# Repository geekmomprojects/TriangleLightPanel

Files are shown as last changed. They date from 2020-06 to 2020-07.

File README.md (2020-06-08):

# TriangleLightPanel
 
Triangle LED Light Panel TriangleBoards
 
Files for modular "Nanoleaf" style connecting LED PCBs. Each triangular board contains three 4020 Side-Emitting SK6812 LEDs, which diffuse their light into a translucent acrylic cover panel. The triangular LED boards are connected via smaller rectangular connector PCBs using a system of pressure contacts and pads. 

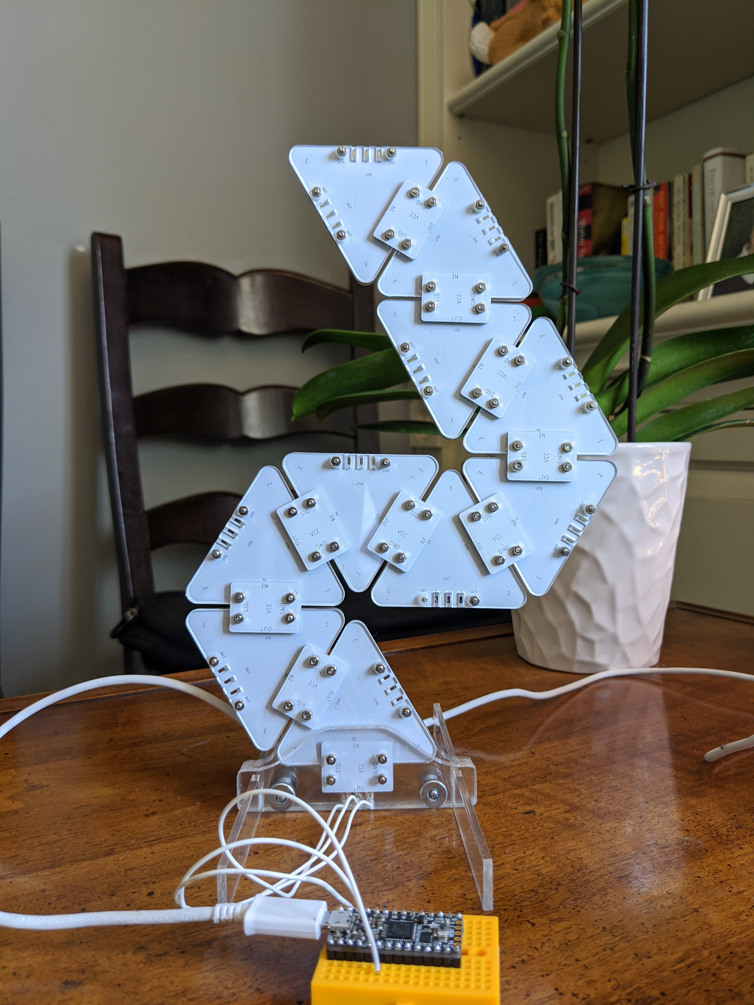
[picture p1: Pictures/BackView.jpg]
Board Connectors


This repository contains Eagle CAD files for the Triangle LED boards and connector boards. Be warned that SMT soldering 4020 side-emitting LEDs is *very* tricky if you decide to make your own. Best accomplished with solder paste and a reflow oven or hot air gun

A thin layer of 1/16" clear acrylic across the back of each Triangle PCB prevents pressure contacts from being crushed and a layer of 1/8" semi-translucent acrylic diffuses the LEDs on the front side. CAD files for each are included and will need to be laser cut. Link to best diffusion acrylic I've found to use is in the BOM.

All pieces held together with M2 screws (10mm) and nuts. The full assembly can stand freely without being wall mounted.

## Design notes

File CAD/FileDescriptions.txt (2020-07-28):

CAD Files:

"DiffusionLayerAcrylic.svg" to be cut from 1/8" semi-translucent acrylic, sits on the front of the triangle PCB to diffuse light from side emitting LEDs. 
"BufferLayerAcrylic.svg" to be cut from 1/16" clear acrylic, sits on back of triangle PCB to prevent pressure contacts from being crushed

See BOM.xls for sourcing details

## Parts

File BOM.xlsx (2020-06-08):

PCB Components
Component | Manfacturer | Part Number | Datasheet | Source | Notes
Pressure Contact | Amphenol | 10104319-009RLF | https://cdn.amphenol-icc.com/media/wysiwyg/files/drawing/10104319.pdf | https://www.digikey.com/product-detail/en/amphenol-icc-fci/10104319-009RLF/609-5377-1-ND/8555648
Side Emitting LED |  | SK6812 4020 Side Emitting RGB LED | https://www.aliexpress.com/item/32965664236.html | https://www.aliexpress.com/item/32965664236.html | Purchased "SIDE old version"
0.1 uF Capacitor (0603) | Samsung | CL10F104ZO8NNNC |  | https://www.digikey.com/product-detail/en/samsung-electro-mechanics/CL10F104ZO8NNNC/1276-1258-1-ND/3889344
Acrylic
1/8" Semi-Translucent Acrylic Sheet for LED diffusion | Rowmark | ROWMARK COLORHUES PHANTOM TRANSLUCENT ENGRAVING PLASTIC |  | https://www.jpplus.com/rowmark-colorhues-phantom-translucent-engraving-plastic
1/16" Clear Acrylic sheet to buffer pressure contacts
Hardware
M2 Screws (10mm)
M2 Nuts

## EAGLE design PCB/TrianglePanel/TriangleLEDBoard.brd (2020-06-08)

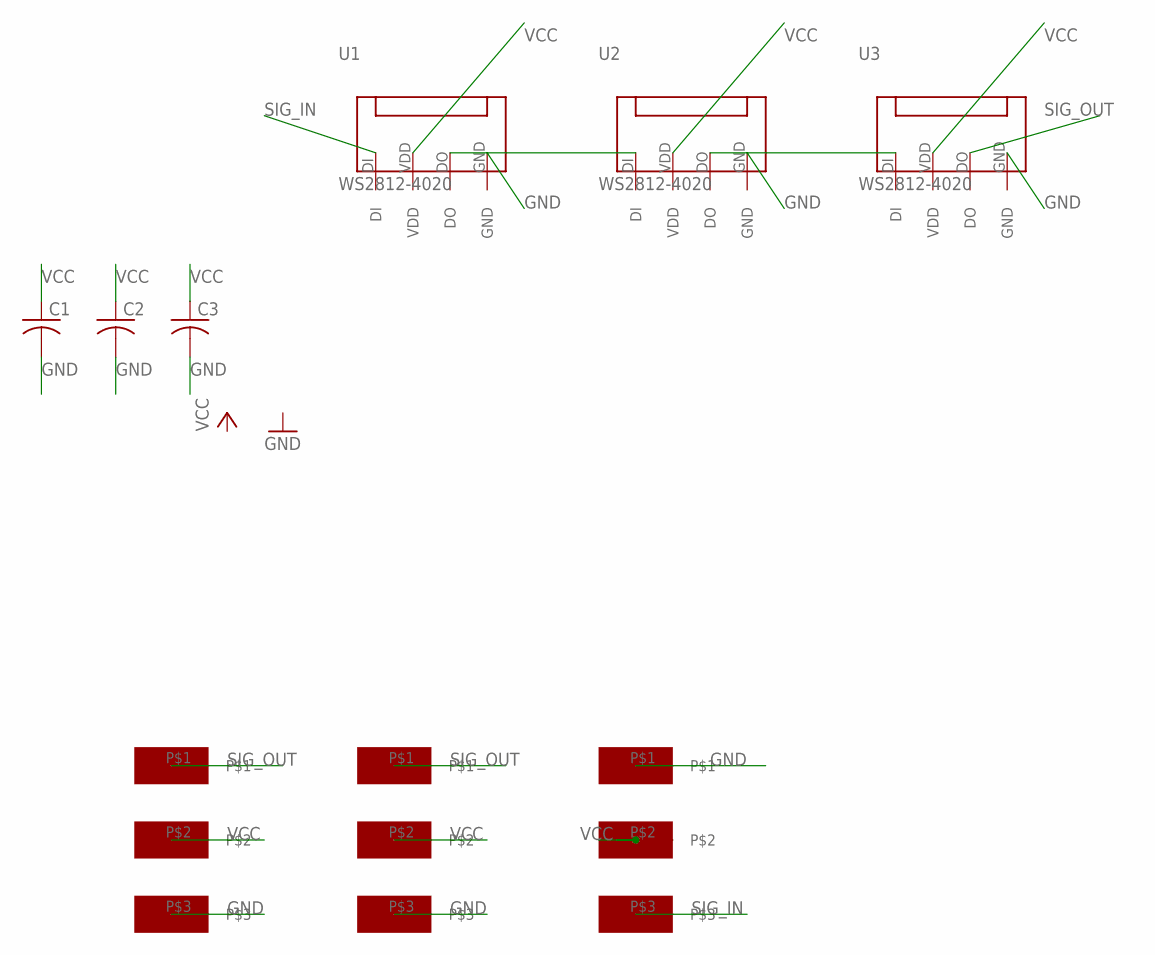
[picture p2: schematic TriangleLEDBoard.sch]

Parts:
C1, C2, C3: C-USC0603; C0603
U1, U2, U3: WS2812-4020; WS2812B_4020
U$1, U$2, U$3: 3_CONTACT_PADS_5_MM_SPACING_WITH_HOLES; RECTANGULAR_PADS_5_MM_SPACING_WITH_HOLES

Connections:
GND: C1.2, C2.2, C3.2, U1.GND, U2.GND, U3.GND, U$1.P$1, U$2.P$3, U$3.P$3
unnamed: U1.DO, U2.DI
unnamed: U2.DO, U3.DI
SIG_IN: U1.DI, U$1.P$3
SIG_OUT: U3.DO, U$2.P$1, U$3.P$1
VCC: C1.1, C2.1, C3.1, U1.VDD, U2.VDD, U3.VDD, U$1.P$2, U$2.P$2, U$3.P$2

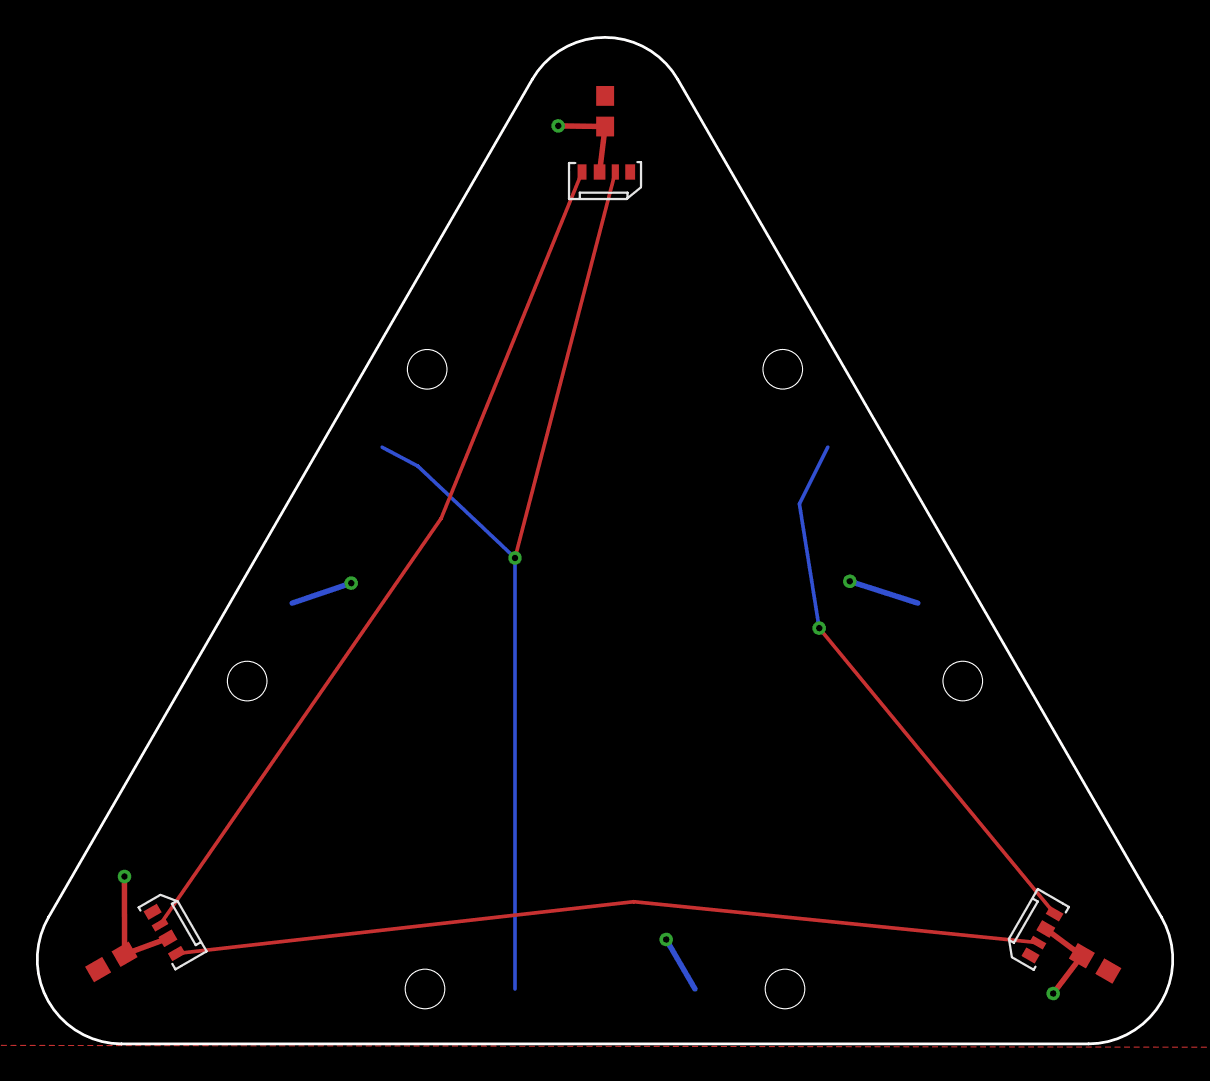
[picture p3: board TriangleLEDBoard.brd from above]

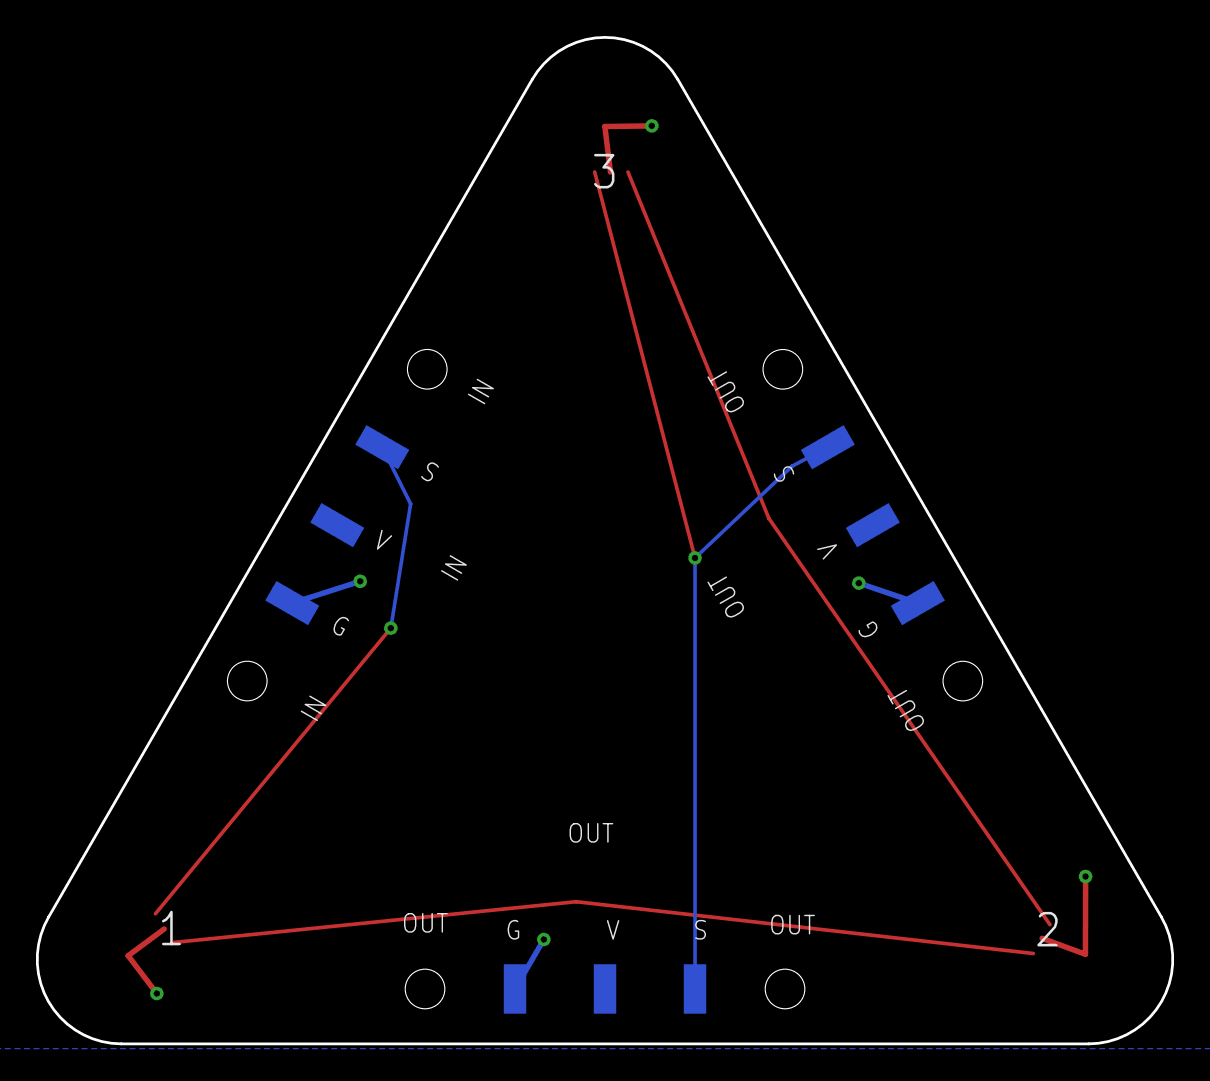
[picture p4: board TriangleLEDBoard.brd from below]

Board: 2 copper layers, 63.1 x 55.9 mm, 9 parts (3 on the bottom side), 6 nets.
